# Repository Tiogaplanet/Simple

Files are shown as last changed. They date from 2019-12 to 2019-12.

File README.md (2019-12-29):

# Simple

 Simple - The Arduino UNO-compatible development system
 
 Created using pin-through hole (PTH) components, Simple is meant to be easy to assemble and modify.  This repository contains the Eagle files necessary to order the printed circuit board.
 
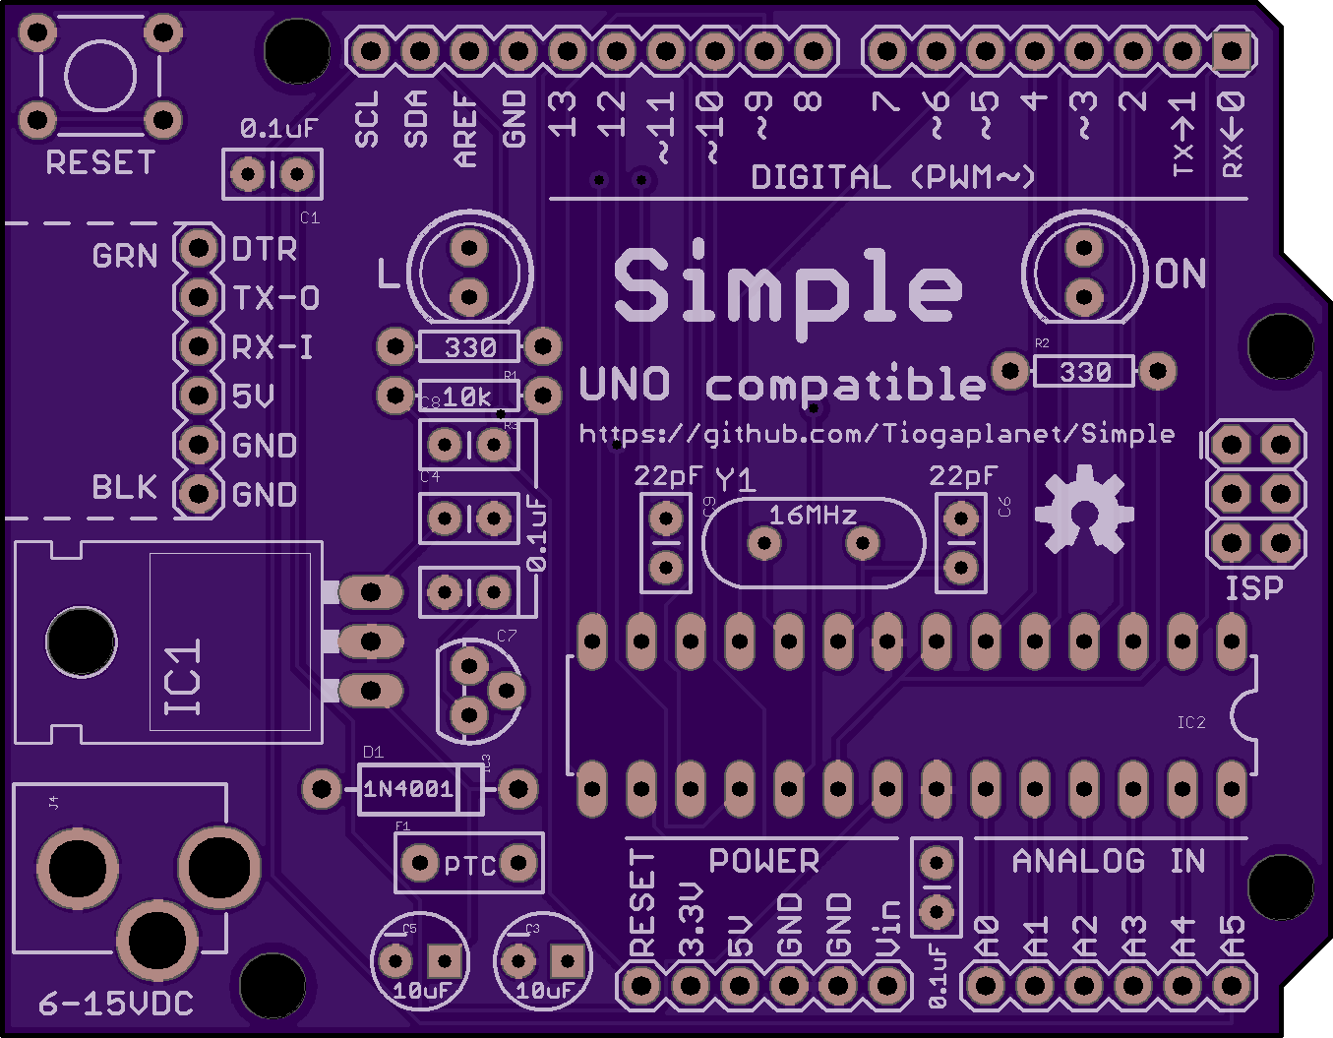
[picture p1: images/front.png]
The top of the board.
 
 
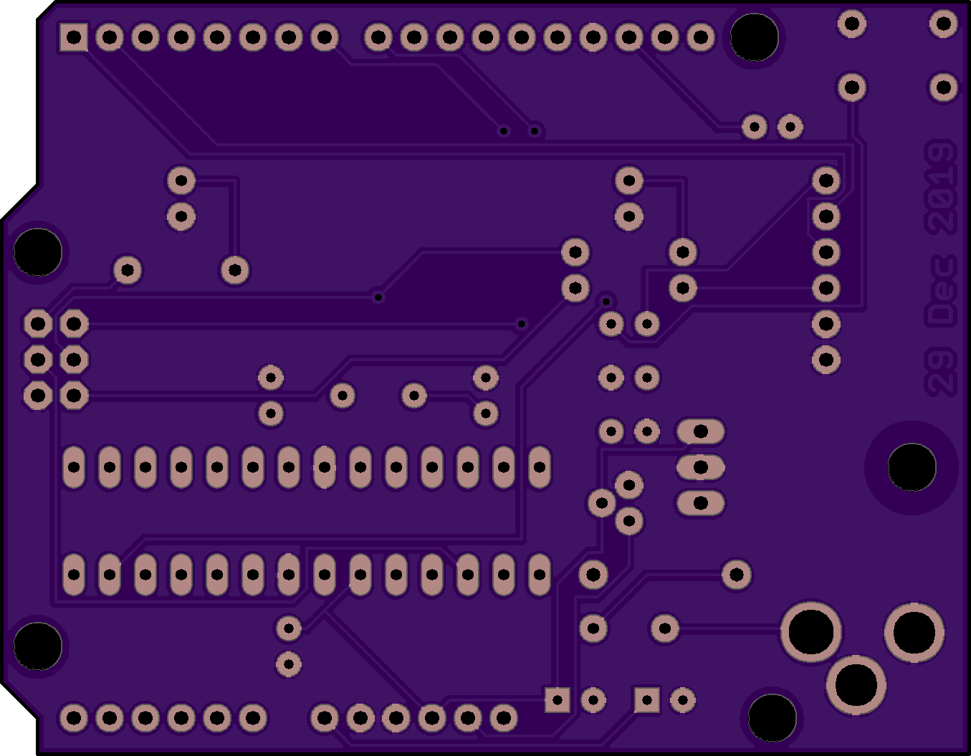
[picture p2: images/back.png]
The bottom of the board.
 

Based on Sparkfun's retired RedBoard PTH kit.

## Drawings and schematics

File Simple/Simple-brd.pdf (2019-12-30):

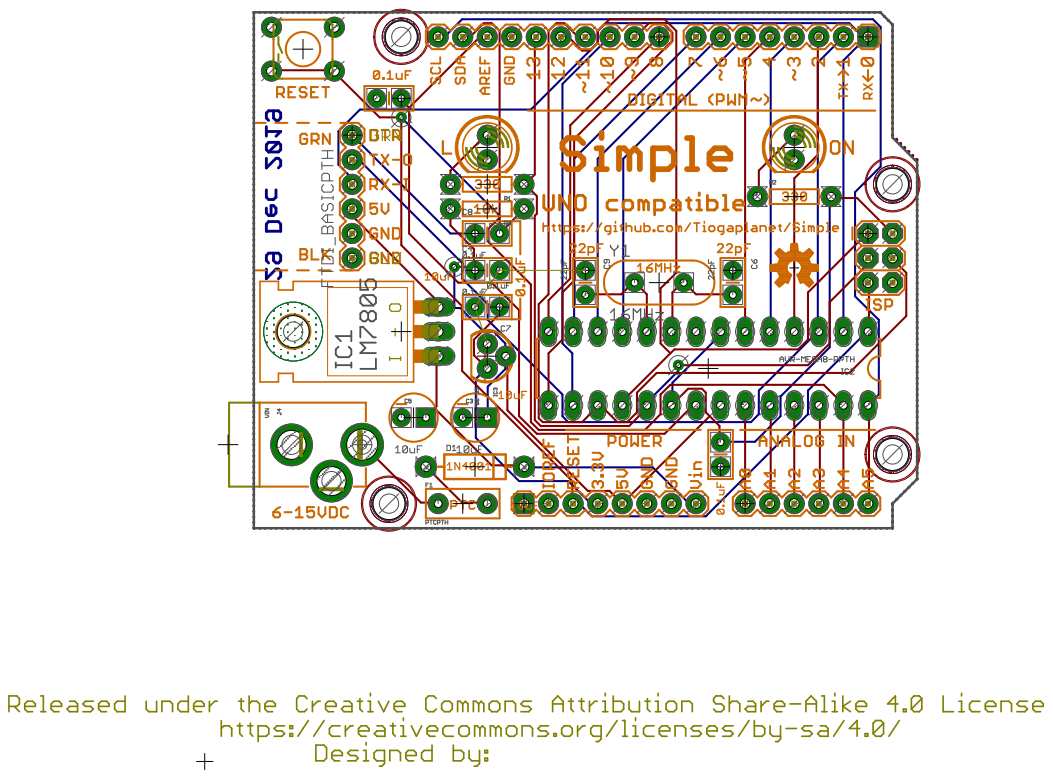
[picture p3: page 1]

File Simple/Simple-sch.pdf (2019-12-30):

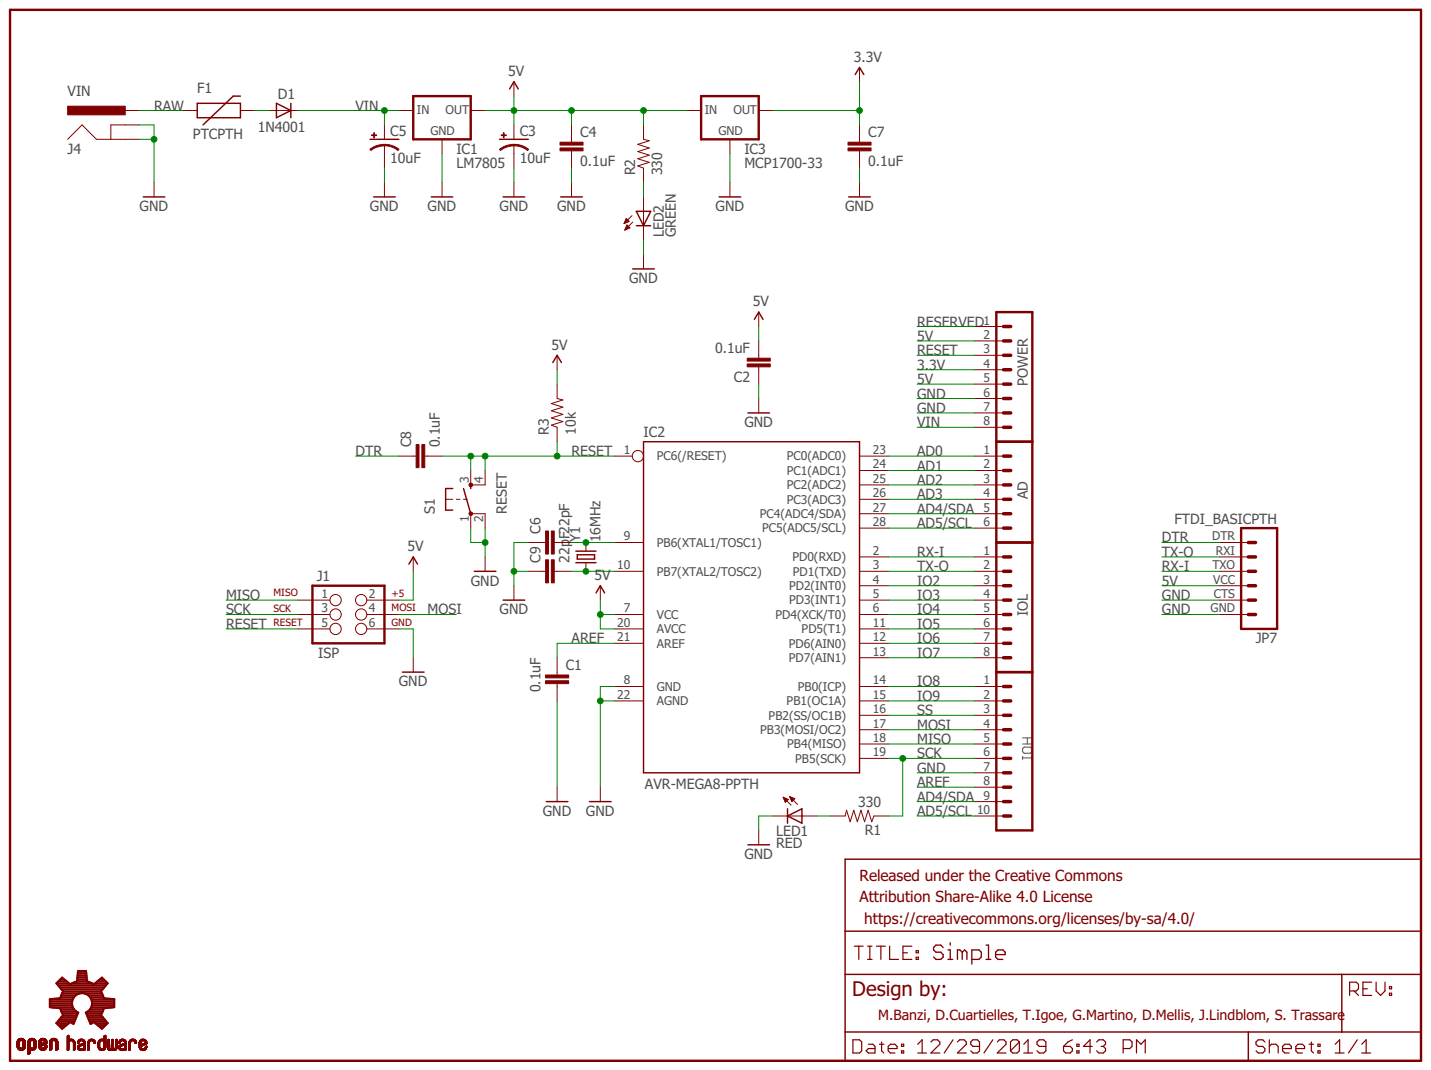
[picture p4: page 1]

Released under the Creative Commons Attribution Share-Alike 4.0 License https://creativecommons.org/licenses/by-sa/4.0/

M.Banzi, D.Cuartielles, T.Igoe, G.Martino, D.Mellis, J.Lindblom, S. Trassare

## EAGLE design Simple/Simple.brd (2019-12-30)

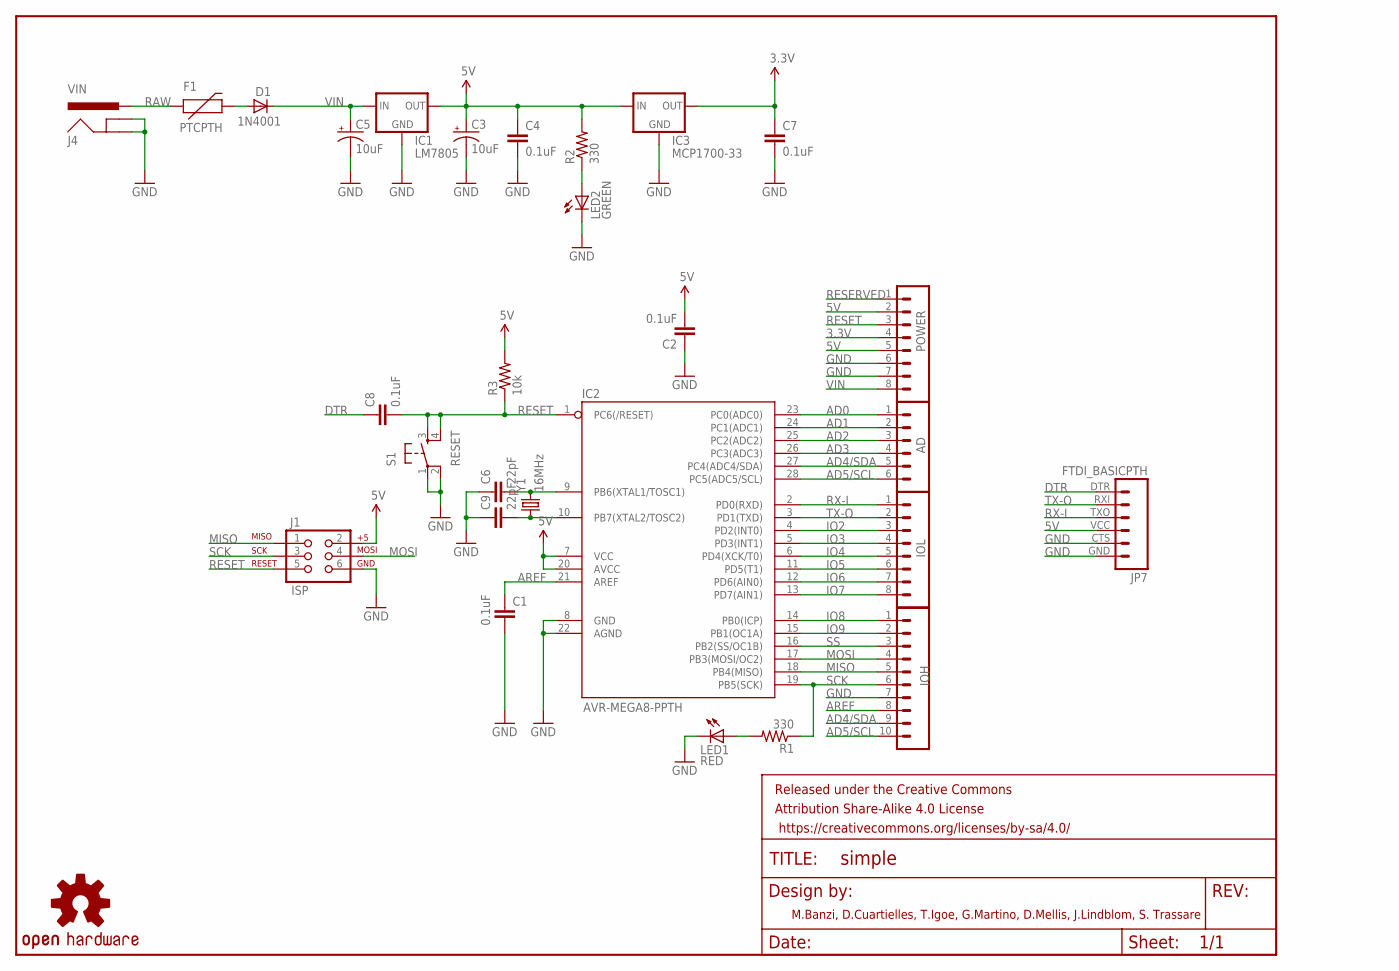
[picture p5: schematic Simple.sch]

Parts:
AD: M06SIP; 1X06
C1, C2, C4, C7, C8: 0.1uF; CAP-PTH-SMALL2
C3, C5: 10uF; CPOL-RADIAL-10UF-25V
C6, C9: 22pF; CAP-PTH-SMALL2
D1: 1N4001; DIODE-1N4001
F1: PTCPTH; PTC
FRAME2: FRAME-LETTER; CREATIVE_COMMONS
IC1: LM7805; TO-220-ALT
IC2: AVR-MEGA8-PPTH; DIL28-3
IC3: MCP1700-33; TO-92
IOH: IOH; 1X10
IOL: M081X08; 1X08
J1: ISP; 2X3
J4: VIN; POWER_JACK_PTH_LOCK
JP7: FTDI_BASICPTH; FTDI_BASIC
LED1: RED; LED5MM
LED2: GREEN; LED5MM
POWER: POWER; 1X08
R1, R2: 330; AXIAL-0.3
R3: 10k; AXIAL-0.3
S1: RESET; TACTILE-PTH
U$7: OSHW-LOGOM; OSHW-LOGO-M
Y1: 16MHz; HC49US

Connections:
3.3V: C7.1, IC3.3 (OUT), POWER.4
5V: C2.2, C3.1 (+), C4.1, IC1.OUT, IC2.7 (VCC), IC2.20 (AVCC), IC3.2 (IN), J1.2, JP7.VCC (4), POWER.5, R2.P$2 (2), R3.P$2 (2)
AD0: AD.1, IC2.23 (PC0(ADC0))
AD1: AD.2, IC2.24 (PC1(ADC1))
AD2: AD.3, IC2.25 (PC2(ADC2))
AD3: AD.4, IC2.26 (PC3(ADC3))
AD4/SDA: AD.5, IC2.27 (PC4(ADC4/SDA)), IOH.9
AD5/SCL: AD.6, IC2.28 (PC5(ADC5/SCL)), IOH.10
AREF: C1.1, IC2.21 (AREF), IOH.8
DTR: C8.1, JP7.DTR (1)
GND: C1.2, C2.1, C3.2 (-), C4.2, C5.2 (-), C6.1, C7.2, C9.1, IC1.GND, IC2.8 (GND), IC2.22 (AGND), IC3.1 (GND), IOH.7, J1.6, J4.GND, J4.GNDBREAK, JP7.CTS (5), JP7.GND (6), LED1.K (C), LED2.K (C), POWER.6, POWER.7, S1.1, S1.2
IO2: IC2.4 (PD2(INT0)), IOL.3
IO3: IC2.5 (PD3(INT1)), IOL.4
IO4: IC2.6 (PD4(XCK/T0)), IOL.5
IO5: IC2.11 (PD5(T1)), IOL.6
IO6: IC2.12 (PD6(AIN0)), IOL.7
IO7: IC2.13 (PD7(AIN1)), IOL.8
IO8: IC2.14 (PB0(ICP)), IOH.1
IO9: IC2.15 (PB1(OC1A)), IOH.2
MISO: IC2.18 (PB4(MISO)), IOH.5, J1.1
MOSI: IC2.17 (PB3(MOSI/OC2)), IOH.4, J1.4
unnamed: LED1.A, R1.P$2 (2)
unnamed: LED2.A, R2.P$1 (1)
unnamed: C6.2, IC2.9 (PB6(XTAL1/TOSC1)), Y1.2
unnamed: C9.2, IC2.10 (PB7(XTAL2/TOSC2)), Y1.1
unnamed: D1.A, F1.P$2 (2)
RAW: F1.P$1 (1), J4.PWR
RESERVED: POWER.1
RESET: C8.2, IC2.1 (PC6(/RESET)), J1.5, POWER.3, R3.P$1 (1), S1.3, S1.4
RX-I: IC2.2 (PD0(RXD)), IOL.1, JP7.TXO (3)
SCK: IC2.19 (PB5(SCK)), IOH.6, J1.3, R1.P$1 (1)
SS: IC2.16 (PB2(SS/OC1B)), IOH.3
TX-O: IC2.3 (PD1(TXD)), IOL.2, JP7.RXI (2)
VIN: C5.1 (+), D1.C, IC1.IN, POWER.8

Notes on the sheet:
M.Banzi, D.Cuartielles, T.Igoe, G.Martino, D.Mellis, J.Lindblom, S. Trassare

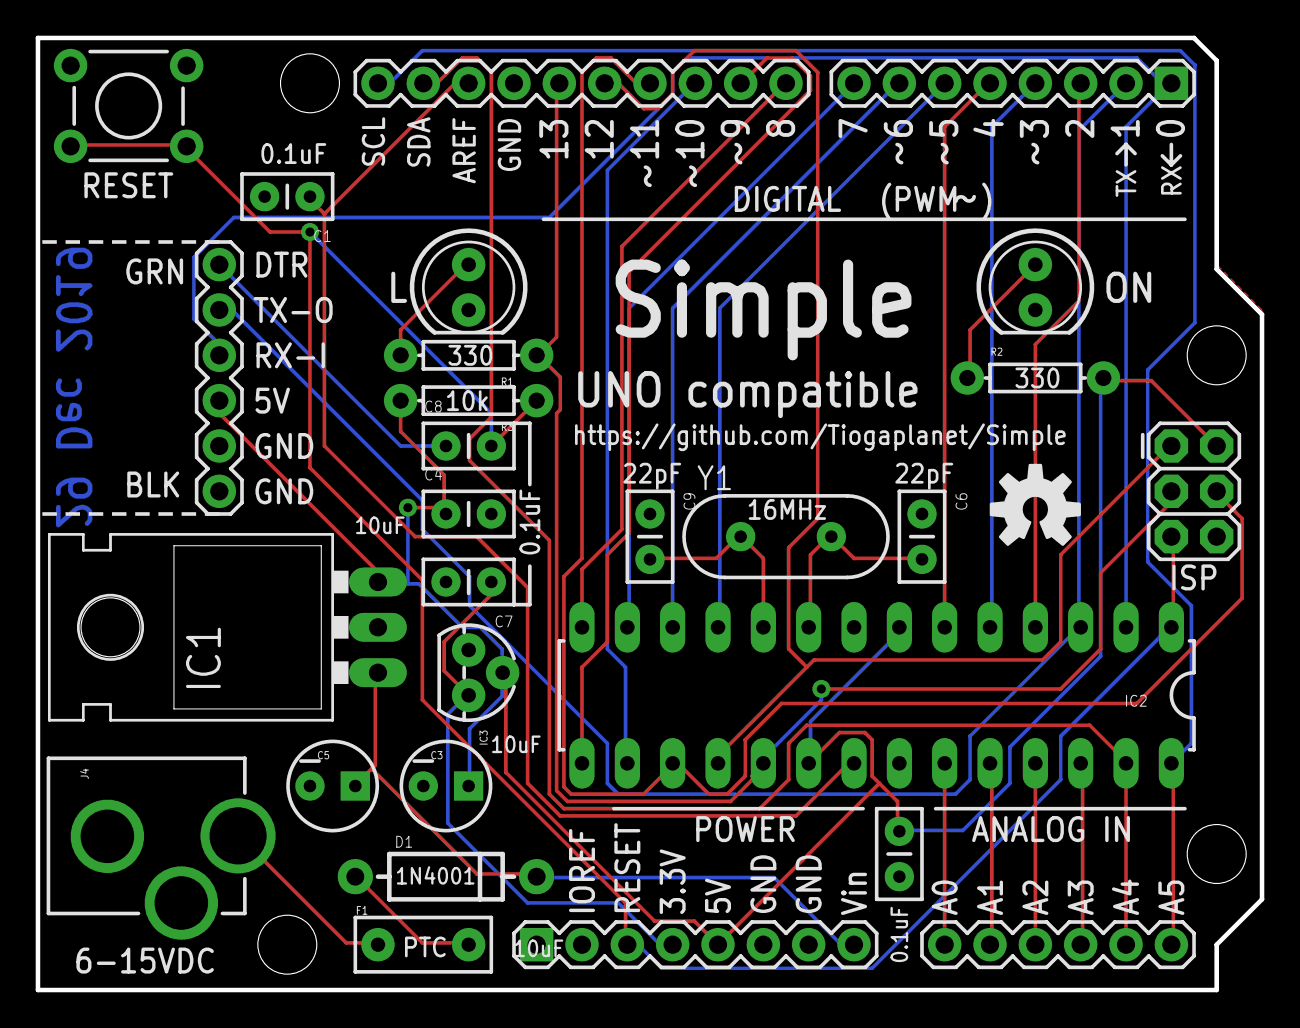
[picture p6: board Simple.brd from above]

Board: 2 copper layers, 68.6 x 53.3 mm, 34 parts (0 on the bottom side), 33 nets.

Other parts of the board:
JP1, JP2, JP3, JP6: STAND-OFF

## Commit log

2019-12-29 Initial commit
    Be it called my own modification. My take on the Arduino UNO board. Based on Sparkfun's retired RedBoard PTH kit.
    [Simple.brd, Simple.sch]
2019-12-30 Added IOREF and reserved pins
    [Simple.brd, Simple.sch]

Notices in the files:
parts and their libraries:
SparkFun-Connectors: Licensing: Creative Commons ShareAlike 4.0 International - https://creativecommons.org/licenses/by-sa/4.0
